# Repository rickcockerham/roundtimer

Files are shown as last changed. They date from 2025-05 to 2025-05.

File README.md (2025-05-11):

# Judo Class Round Timer ⏱️🥋
 
A round timer for martial arts/boxing/whatever.

This project is a compact, battery-powered round timer designed for martial arts classes like judo. It uses an Adafruit Trinket M0, an I2C alphanumeric LED display, and a piezo buzzer to provide audible round signals.  This is used by us at https://austinjudo.club

I've included the FreeCad file for the box.

I need distractions while I'm working on my AI Stock Trader at https://ai-stocktrading.com

---

## 🔧 Features

- Selectable round durations: **30, 45, 60, 120, 180, or 300 seconds**
- **Start/Pause button** with audible feedback
- **Looping rounds**: automatically restarts after each round ends
- **Onboard RGB LED flash** and buzzer at round end
- **Volume control** via button combo
- **Sound style selection** via button combo (10 unique sounds)
- **3-digit countdown display**
- **Sleep mode** after 5 minutes of inactivity (wakes on button press)
- Stores settings (volume, interval, sound) in onboard flash
- Powered by a **3.7V LiPo battery** with a USB charger
- Runs for many sessions on a single charge

---

## 🛠️ Hardware

| Component | Purpose |
|---|---|
| Adafruit Trinket M0 | Main controller |
https://www.adafruit.com/product/3500
| Adafruit Alphanumeric Display | 4-character countdown display (I²C)|
https://www.adafruit.com/product/879
| Piezo buzzer w/ driver        | Audible round signal               |
https://www.adafruit.com/product/5791
| USB LiPo charger              | Recharge battery between classes.  |
https://www.adafruit.com/product/1905
| Power switch                  | Power off between classes.         |
| 2x pushbuttons                | Mode and Start/Pause               |
| LiPo battery (3.7V)           | Power source                       |

---

## 🔌 Pin Connections

| Trinket M0 Pin | Connected Device |
|---|---|
| BAT | LiPo Battery + |
| GND | Battery –, display GND, button GNDs |
| 3V | Display VCC |
| 0 (SCL) | Display SCL |
| 2 (SDA) | Display SDA |
| 1 | Buzzer IN |
| 3 | MODE button |
| 4 | START/PAUSE button |
| 7 (DotStar DI) | Onboard RGB data (internal) |
| 8 (DotStar CI) | Onboard RGB clock (internal) |

---

## 🧠 Controls

| Action | Result |
|---|---|
| Tap **MODE** | Change duration or reset if running |
| Tap **START** | Start or pause timer |
| Hold **START**, tap **MODE** | Cycle volume 1–9 |
| Hold **MODE**, tap **START** | Cycle sound style (0–9) |

---

## 💾 Flash Memory

Settings are saved using `FlashStorage`:
- Volume: 1–9
- Interval: 0–5 (maps to 30–300 seconds)
- Sound index: 0–9

---

## 💤 Power Saving

- Sleeps after **5 minutes** of inactivity
- Wakes instantly on any button press
- RGB and buzzer are disabled while asleep

---

## 📷 Project Photos

---

## 📜 License

This project is licensed under the MIT License. Feel free to modify and reuse!

---

## 🙌 Acknowledgments

- Adafruit for their Trinket M0 and display libraries.  Lady Ada is awesome!
- Arduino for platform support
- The students of Austin Judo Club 🥋  https://austinjudo.club

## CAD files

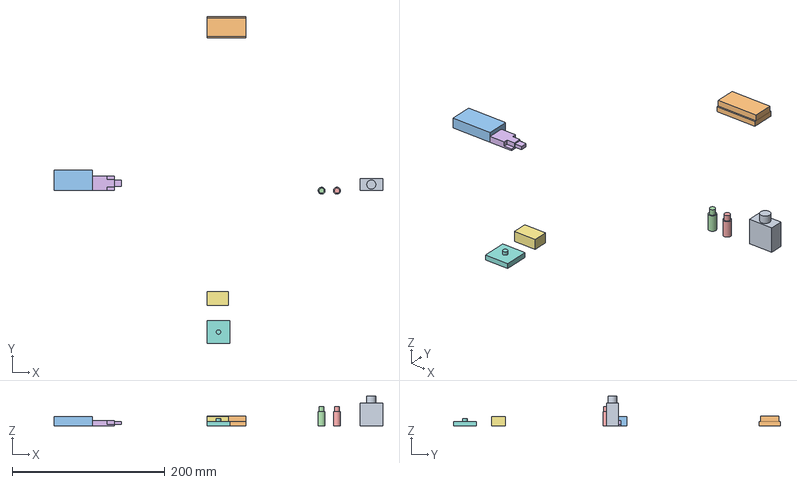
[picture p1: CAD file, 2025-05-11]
RoundTimerCad/RoundTimer.FCStd
430.0 x 428.0 x 39.0 mm
Awesome switch
LCD Display
Lipo Battery
Push Button mode/reset
Push Button start/stop
USB Battery Charger
Piezo Driver
Piezo Buzzer

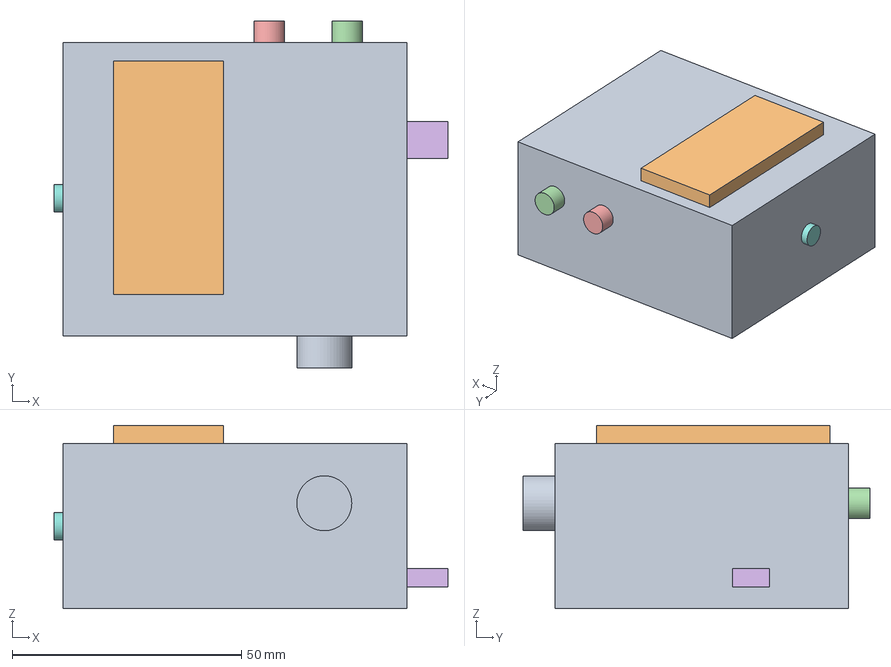
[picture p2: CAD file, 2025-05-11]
RoundTimerCad/RoundTimer-precuts.FCStd
86.0 x 75.7 x 40.0 mm
Awesome switch
LCD Display
Lipo Battery
Push Button mode/reset
Push Button start/stop
USB Battery Charger
Piezo Driver
Piezo Buzzer
OuterBox
InnerBox

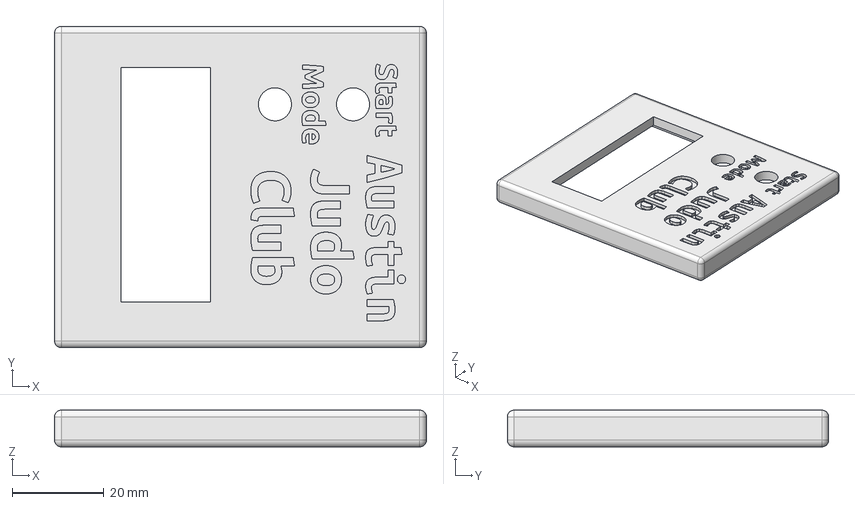
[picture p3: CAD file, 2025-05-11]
RoundTimerCad/RoundTimer-lid.FCStd
81.0 x 70.0 x 8.00 mm

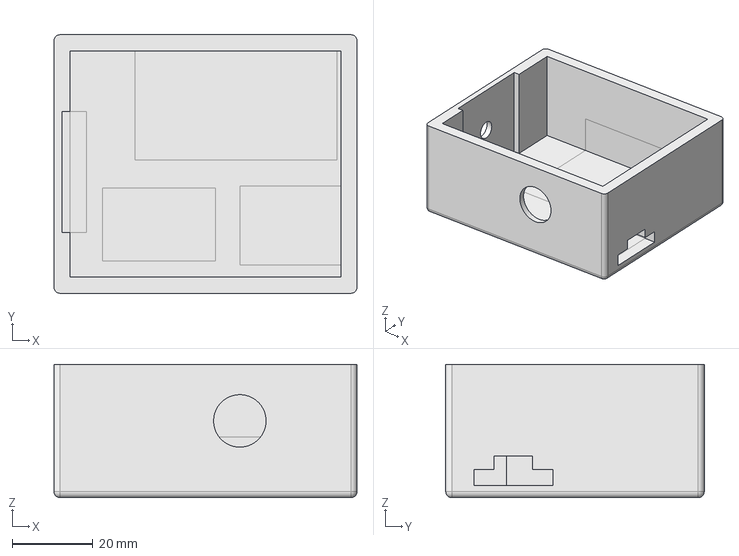
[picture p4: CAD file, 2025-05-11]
RoundTimerCad/RoundTimer-box.FCStd
75.0 x 64.0 x 33.0 mm

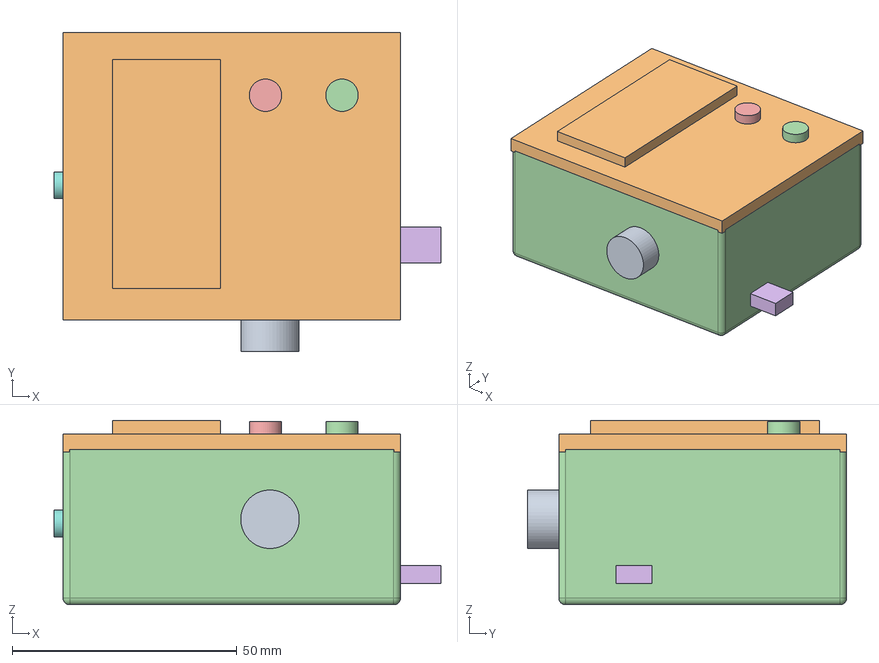
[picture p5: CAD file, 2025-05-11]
RoundTimerCad/RoundTimer-partsonly.FCStd
86.0 x 71.0 x 41.0 mm
Awesome switch
LCD Display
Lipo Battery
Push Button mode/reset
Push Button start/stop
USB Battery Charger
Piezo Driver
Piezo Buzzer
InnerBox
LidRemove
Arduino

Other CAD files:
RoundTimerCad/RoundTimer-box.stl
RoundTimerCad/RoundTimer-lid.stl
RoundTimerCad/RoundTimer.stl

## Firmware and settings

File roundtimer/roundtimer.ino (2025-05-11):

#include <Wire.h>
#include <Adafruit_GFX.h>
#include <Adafruit_LEDBackpack.h>
#include <FlashStorage.h>
#include <Adafruit_DotStar.h>
#include <SPI.h>

#define DEBUG false
#define NUMPIXELS 1
#define BUTTON_MODE  3
#define BUTTON_START 4
#define BUZZER_PIN   1
#define MAX_DURATION 9 //length of the tone
#define MAX_SOUNDS 9  // tone number
#define SLEEP_TIMEOUT 300000
const int intervals[] = {30, 45, 60, 120, 180, 300};
#define NUM_INTERVALS 6

Adafruit_7segment display = Adafruit_7segment();

struct Settings {
  uint8_t duration;      // 1–MAX_DURATION
  uint8_t interval;    // 0–4
  uint8_t soundIndex;  // 0–MAX_SOUNDS
};
FlashStorage(flashStore, Settings);
Settings settings;

int remainingTime = 0;
bool timerRunning = false;
bool sleeping = false;

unsigned long lastUpdate = 0, lastInteraction = 0;
bool lastModeBtn = HIGH, lastStartBtn = HIGH;

Adafruit_DotStar strip(NUMPIXELS, 7, 8, DOTSTAR_BGR);

void setup() {
  if(DEBUG) {Serial.begin(9600); while(!Serial) {}}

  strip.begin();  // Initialize pins for output
  strip.show();   // Turn all LEDs off

  pinMode(BUTTON_MODE, INPUT_PULLUP);
  pinMode(BUTTON_START, INPUT_PULLUP);
  pinMode(BUZZER_PIN, OUTPUT);
  noTone(BUZZER_PIN);

  Wire.begin();
  display.begin(0x70);
  display.setBrightness(3);
  display.clear();
  display.writeDisplay();
  if(DEBUG) Serial.println("Display initialized");

  settings = flashStore.read();
  if (settings.duration < 1 || settings.duration > MAX_DURATION) settings.duration = 1;
  if (settings.interval >= NUM_INTERVALS) settings.interval = 0;
  if (settings.soundIndex < 0 || settings.soundIndex > MAX_SOUNDS) settings.soundIndex = 0;

  remainingTime = intervals[settings.interval];
  sleeping = false;

  if(DEBUG) {
    Serial.print("Loaded duration: ");
    Serial.println(settings.duration);
    Serial.print("Loaded interval index: ");
    Serial.println(settings.interval);
    Serial.print("Loaded sound index: ");
    Serial.println(settings.soundIndex);
    Serial.print("Initial remainingTime: ");
    Serial.println(remainingTime);
  }
}

void loop() {
  handleButtons();

  if (timerRunning && millis() - lastUpdate >= 1000) {
    lastUpdate = millis();
    remainingTime--;
    if(DEBUG) Serial.print("Timer tick: ");
    if(DEBUG) Serial.println(remainingTime);

    if (remainingTime <= 0) {
      if(DEBUG) Serial.println("Timer reached 0. Buzz + Reset");
      strip.setPixelColor(0, strip.Color(255, 0, 255));  // PURPLE
      strip.show();
      playBuzzerTone(settings.soundIndex);
      blinkDisplay();
      strip.setPixelColor(0, strip.Color(0, 0, 0));    // Off
      strip.show();
      remainingTime = intervals[settings.interval];
    }
  }

  if(!sleeping) displayTime();

  if (!timerRunning && millis() - lastInteraction > SLEEP_TIMEOUT) {
    if(DEBUG) Serial.println("Inactivity timeout. Going to sleep.");
    sleepNow();
  }
}

void handleButtons() {
  bool modeBtn = digitalRead(BUTTON_MODE);
  bool startBtn = digitalRead(BUTTON_START);
  bool save = false;

  if (modeBtn == LOW || startBtn == LOW || timerRunning) {
    lastInteraction = millis();
    sleeping = false;
  }

  // Duration cycle: hold START, tap MODE
  if (startBtn == LOW && lastStartBtn == LOW && modeBtn == LOW && lastModeBtn == HIGH) {
    settings.duration += 1;
    if (settings.duration > MAX_DURATION) settings.duration = 1;
    if(DEBUG) Serial.print("Duration changed: ");
    if(DEBUG) Serial.println(settings.duration);
    playBuzzerAck();
    blinkSetting((char *)"dur", settings.duration);
    save = true;
  }

  // Sound cycle: hold MODE, tap START
  else if (modeBtn == LOW && lastModeBtn == LOW && startBtn == LOW && lastStartBtn == HIGH) {
    settings.soundIndex++;
    if (settings.soundIndex > MAX_SOUNDS) settings.soundIndex = 0;
    if(DEBUG) Serial.print("Sound changed: ");
    if(DEBUG) Serial.println(settings.soundIndex);
    playBuzzerAck();
    blinkSetting((char *)"tun", settings.soundIndex);
    save = true;
  }

  // MODE tapped
  else if (modeBtn == LOW && lastModeBtn == HIGH && startBtn == HIGH) {
    if (timerRunning || remainingTime < intervals[settings.interval]) {
      remainingTime = intervals[settings.interval];
      if(DEBUG) Serial.println("MODE tap: timer running — reset to interval time");
      timerRunning = false;
    } else {
      settings.interval = (settings.interval + 1) % NUM_INTERVALS;
      remainingTime = intervals[settings.interval];
      if(DEBUG) {
        Serial.print("Interval changed: ");
        Serial.print(settings.interval);
        Serial.print(" => ");
        Serial.println(remainingTime);
      }
      save = true;
    }
    playBuzzerAck();
  }

  // START tapped
  else if (startBtn == LOW && lastStartBtn == HIGH && modeBtn == HIGH) {
    timerRunning = !timerRunning;
    if(DEBUG) Serial.print("START tapped: timerRunning = "); Serial.println(timerRunning);
    playBuzzerTone(settings.soundIndex);
  }

  if (save) {
    flashStore.write(settings);
    if(DEBUG) Serial.println("Settings saved to flash.");
  }

  lastModeBtn = modeBtn;
  lastStartBtn = startBtn;
}
void displayTime() {
  display.println(remainingTime);
  display.writeDisplay();
}

void blinkDisplay() {
  display.print(0x8888, HEX);
  display.writeDisplay();
  delay(100);
  display.clear();
  display.writeDisplay();
  delay(60);
}

void blinkSetting(char *c, int v) {
  display.clear();
  char buf[5];
  snprintf(buf, sizeof(buf), "%3s%1d", c, v);

  display.print(buf);
  display.writeDisplay();
  delay(500);
  display.clear();
  display.writeDisplay();
}

void playBuzzerAck() {
  tone(BUZZER_PIN, 50);
  delay(100);
  noTone(BUZZER_PIN);
}

void playBuzzerTone(int idx) {
  int d = (settings.duration+1) * 3;
  if(DEBUG) Serial.print("Playing tone #"); Serial.println(idx);

  switch (idx) {
    case 0:  for (int f = 1; f < 15; f += 1) { tone(BUZZER_PIN, 400); delay(20+d); noTone(BUZZER_PIN); delay(10);} break;
    case 1: tone(BUZZER_PIN, 250); delay(100+d); tone(BUZZER_PIN, 100); delay(100+d); tone(BUZZER_PIN, 250); break;
    case 2: for (int f = 700; f > 200; f -= 20) { tone(BUZZER_PIN, f); delay(5+d); } break;
    case 3: for (int f = 200; f < 700; f += 20) { tone(BUZZER_PIN, f); delay(5+d); } break;
    case 4: tone(BUZZER_PIN, 300); break;
    case 5: tone(BUZZER_PIN, 700); delay(50+d);
            tone(BUZZER_PIN, 900); delay(50+d);
            tone(BUZZER_PIN, 300); break;
    case 6: tone(BUZZER_PIN, 900); delay(70+d);
            tone(BUZZER_PIN, 1100); delay(70+d);
            tone(BUZZER_PIN, 700); break;
    case 7: tone(BUZZER_PIN, 300); delay(90+d);
            tone(BUZZER_PIN, 500); delay(90+d);
            tone(BUZZER_PIN, 800); break;
    case 8: for (int f = 1000; f > 200; f -= 30) { tone(BUZZER_PIN, f); delay(3+d); } break;
    case 9:for (int f = 800; f > 100; f -= 40) { tone(BUZZER_PIN, f); delay(3+d); }
            delay(100+d); tone(BUZZER_PIN, 2000); break;
  }
  delay(100+d);
  noTone(BUZZER_PIN);
}

void sleepNow() {
  display.clear();
  display.writeDisplay();
  noTone(BUZZER_PIN);

  attachInterrupt(BUTTON_MODE, wake, FALLING);
  attachInterrupt(BUTTON_START, wake, FALLING);

  //USBDevice.detach();
  if(DEBUG) Serial.println("Entering sleep...");

  __WFI();  // Wait For Interrupt

  //USBDevice.attach();
  detachInterrupt(BUTTON_MODE);
  detachInterrupt(BUTTON_START);
  if(DEBUG) Serial.println("Woke from sleep.");
  lastInteraction = millis();
  sleeping = true;
}

void wake() {
  // Needed to wake from WFI
  sleeping = false;
  lastInteraction = millis();
  displayTime();
}
